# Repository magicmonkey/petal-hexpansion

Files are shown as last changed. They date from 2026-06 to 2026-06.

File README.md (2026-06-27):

A "petal" hexpansion for the EMFcamp Tildagon badge.

It has 3 bands of LEDs which are individually controllable via I2C, using the AL5887 chip.

PCB schematics are in this repo, and the badge app software is in https://github.com/magicmonkey/petal-hexpansion-software

Use the "Petals" app in the badge app store to see some LED animations.

Example image

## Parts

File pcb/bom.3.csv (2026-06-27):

Comment | Designator | Footprint | JLCPCB Part #（optional）
3.6k | R1-3 | 0603 | C22980
Pink LED | D1-19 | 0603 | C2977076
AL5887 | U1 | W-QFN6060-52 | C5583342
Yellow LED | D20-31 | 0603 | C965805
Blue LED | D32-36 | 0603 | C965809
1uF | C1 | 0603 | C1592

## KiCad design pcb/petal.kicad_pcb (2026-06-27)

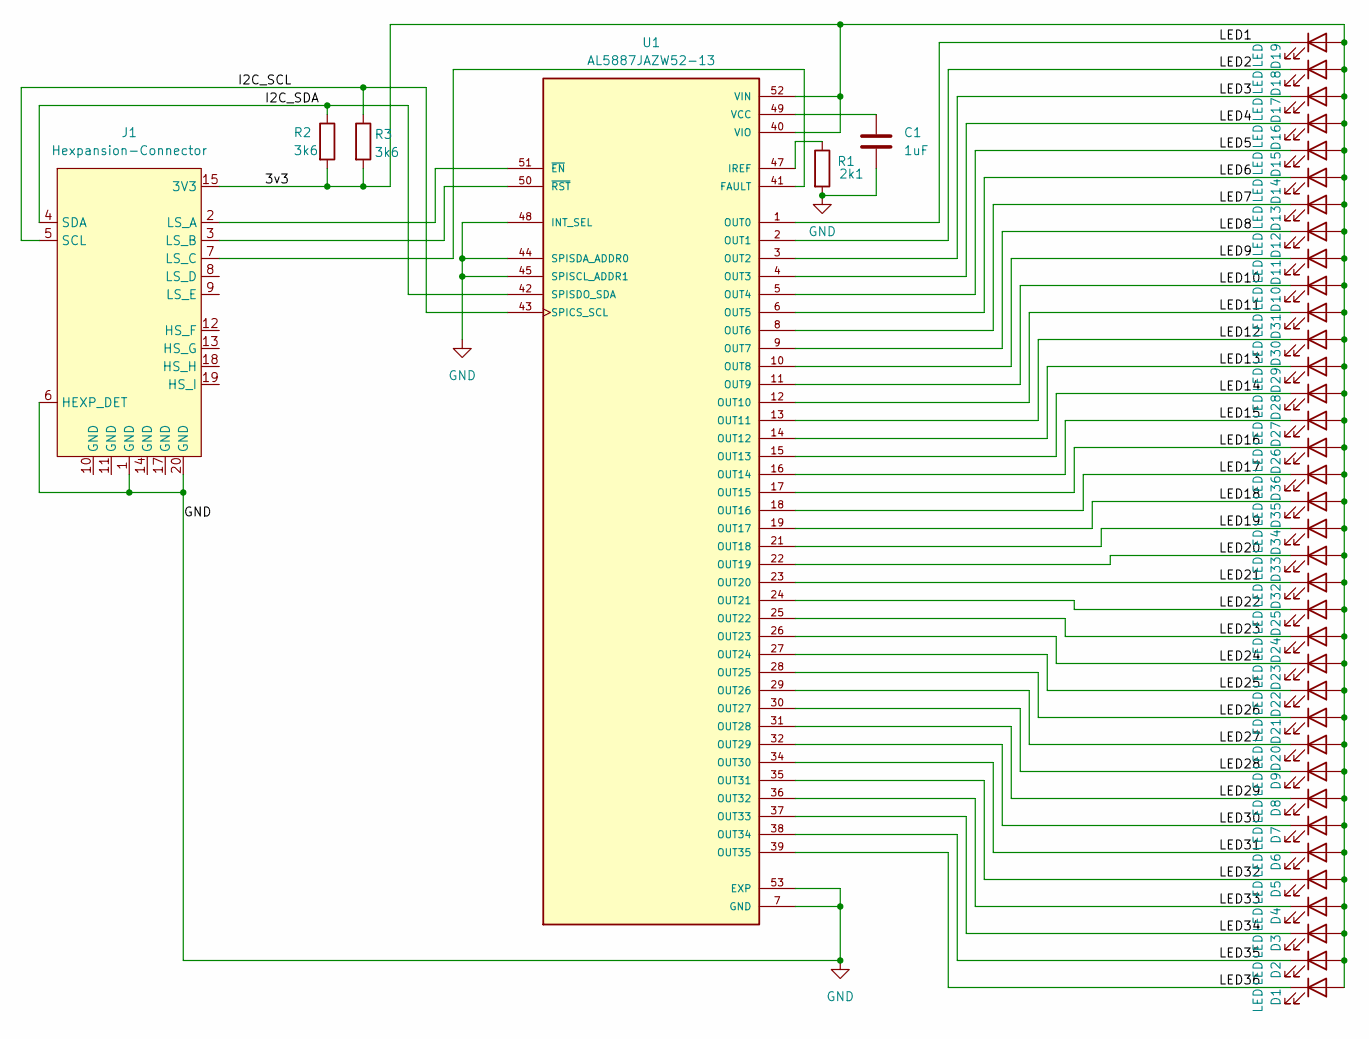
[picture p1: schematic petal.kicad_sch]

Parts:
C1: 1uF; C_0603_1608Metric
D1, D2, D3, D4, D5, D6, D7, D8, D9, D10, D11, D12, D13, D14, D15, D16, D17, D18, D19, D20, D21, D22, D23, D24, D25, D26, D27, D28, D29, D30, D31, D32, D33, D34, D35, D36: LED; LED_0603_1608Metric
J1: Hexpansion-Connector; hexpansion-edge-connector
R1: 2k1; R_0603_1608Metric
R2, R3: 3k6; R_0603_1608Metric
U1: AL5887JAZW52-13; IC_AL5887JAZW52-13; PARTREV 4-2

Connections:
/3v3: D1.2 (A), D2.2 (A), D3.2 (A), D4.2 (A), D5.2 (A), D6.2 (A), D7.2 (A), D8.2 (A), D9.2 (A), D10.2 (A), D11.2 (A), D12.2 (A), D13.2 (A), D14.2 (A), D15.2 (A), D16.2 (A), D17.2 (A), D18.2 (A), D19.2 (A), D20.2 (A), D21.2 (A), D22.2 (A), D23.2 (A), D24.2 (A), D25.2 (A), D26.2 (A), D27.2 (A), D28.2 (A), D29.2 (A), D30.2 (A), D31.2 (A), D32.2 (A), D33.2 (A), D34.2 (A), D35.2 (A), D36.2 (A), J1.15 (3V3), J1.16 (3V3), R2.2, R3.2, U1.40 (VIO), U1.52 (VIN)
/I2C_SCL: J1.5 (SCL), R3.1, U1.43 (SPICS_SCL)
/I2C_SDA: J1.4 (SDA), R2.1, U1.42 (SPISDO_SDA)
/LED1: D19.1 (K), U1.1 (OUT0)
/LED2: D18.1 (K), U1.2 (OUT1)
/LED3: D17.1 (K), U1.3 (OUT2)
/LED4: D16.1 (K), U1.4 (OUT3)
/LED5: D15.1 (K), U1.5 (OUT4)
/LED6: D14.1 (K), U1.6 (OUT5)
/LED7: D13.1 (K), U1.8 (OUT6)
/LED8: D12.1 (K), U1.9 (OUT7)
/LED9: D11.1 (K), U1.10 (OUT8)
/LED10: D10.1 (K), U1.11 (OUT9)
/LED11: D31.1 (K), U1.12 (OUT10)
/LED12: D30.1 (K), U1.13 (OUT11)
/LED13: D29.1 (K), U1.14 (OUT12)
/LED14: D28.1 (K), U1.15 (OUT13)
/LED15: D27.1 (K), U1.16 (OUT14)
/LED16: D26.1 (K), U1.17 (OUT15)
/LED17: D36.1 (K), U1.18 (OUT16)
/LED18: D35.1 (K), U1.19 (OUT17)
/LED19: D34.1 (K), U1.21 (OUT18)
/LED20: D33.1 (K), U1.22 (OUT19)
/LED21: D32.1 (K), U1.23 (OUT20)
/LED22: D25.1 (K), U1.24 (OUT21)
/LED23: D24.1 (K), U1.25 (OUT22)
/LED24: D23.1 (K), U1.26 (OUT23)
/LED25: D22.1 (K), U1.27 (OUT24)
/LED26: D21.1 (K), U1.28 (OUT25)
/LED27: D20.1 (K), U1.29 (OUT26)
/LED28: D9.1 (K), U1.30 (OUT27)
/LED29: D8.1 (K), U1.31 (OUT28)
/LED30: D7.1 (K), U1.32 (OUT29)
/LED31: D6.1 (K), U1.34 (OUT30)
/LED32: D5.1 (K), U1.35 (OUT31)
/LED33: D4.1 (K), U1.36 (OUT32)
/LED34: D3.1 (K), U1.37 (OUT33)
/LED35: D2.1 (K), U1.38 (OUT34)
/LED36: D1.1 (K), U1.39 (OUT35)
GND: C1.2, J1.1 (GND), J1.6 (HEXP_DET), J1.20 (GND), R1.2, U1.7 (GND), U1.20 (GND), U1.33 (GND), U1.44 (SPISDA_ADDR0), U1.45 (SPISCL_ADDR1), U1.46 (GND), U1.48 (INT_SEL), U1.53 (EXP)
unnamed: J1.2 (LS_A), U1.51 (~EN)
unnamed: J1.3 (LS_B), U1.50 (~RST)
unnamed: J1.7 (LS_C), U1.41 (FAULT)
unnamed: R1.1, U1.47 (IREF)
unnamed: C1.1, U1.49 (VCC)

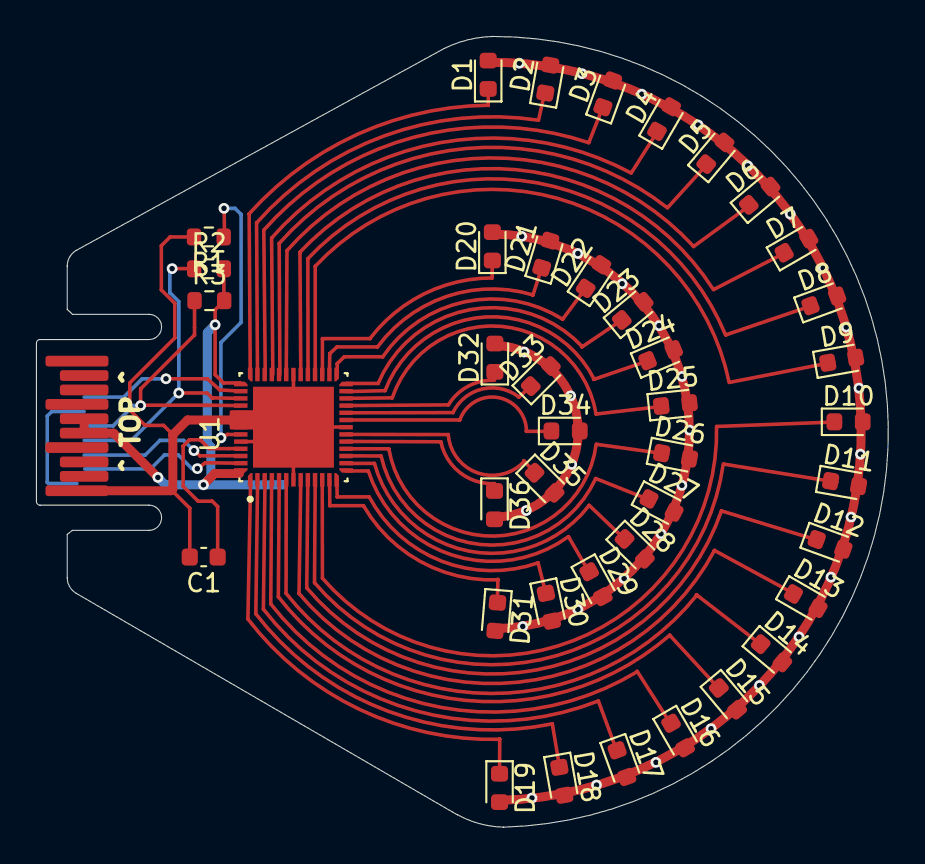
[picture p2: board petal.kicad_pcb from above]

Board: 2 copper layers, 47.3 x 43.9 mm, 42 parts (0 on the bottom side), 45 nets.

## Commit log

2026-06-22 LEDs light up in port 4
2026-06-22 Also turn the LEDs off
2026-06-27 Make room for the schematics
2026-06-27 Add some kind of set of schematic files
    [bom.3.csv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]
2026-06-27 Always start with no LEDs on
2026-06-27 Confetti plugin: a set number of random led-on events
